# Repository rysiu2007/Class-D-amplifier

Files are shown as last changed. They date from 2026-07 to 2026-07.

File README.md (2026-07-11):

# Class-D Amplifier Learning Project

A discrete $200\text{kHz}$ triangle wave generator and Class-D amplifier stage built for learning analog layout and circuit design. 

## Current Status
* **Simulation:** LTspice transient simulations are verified but yet to finish.
* **Hardware:** KiCad PCB design is currently underway, optimized for single-layer hand-etching.

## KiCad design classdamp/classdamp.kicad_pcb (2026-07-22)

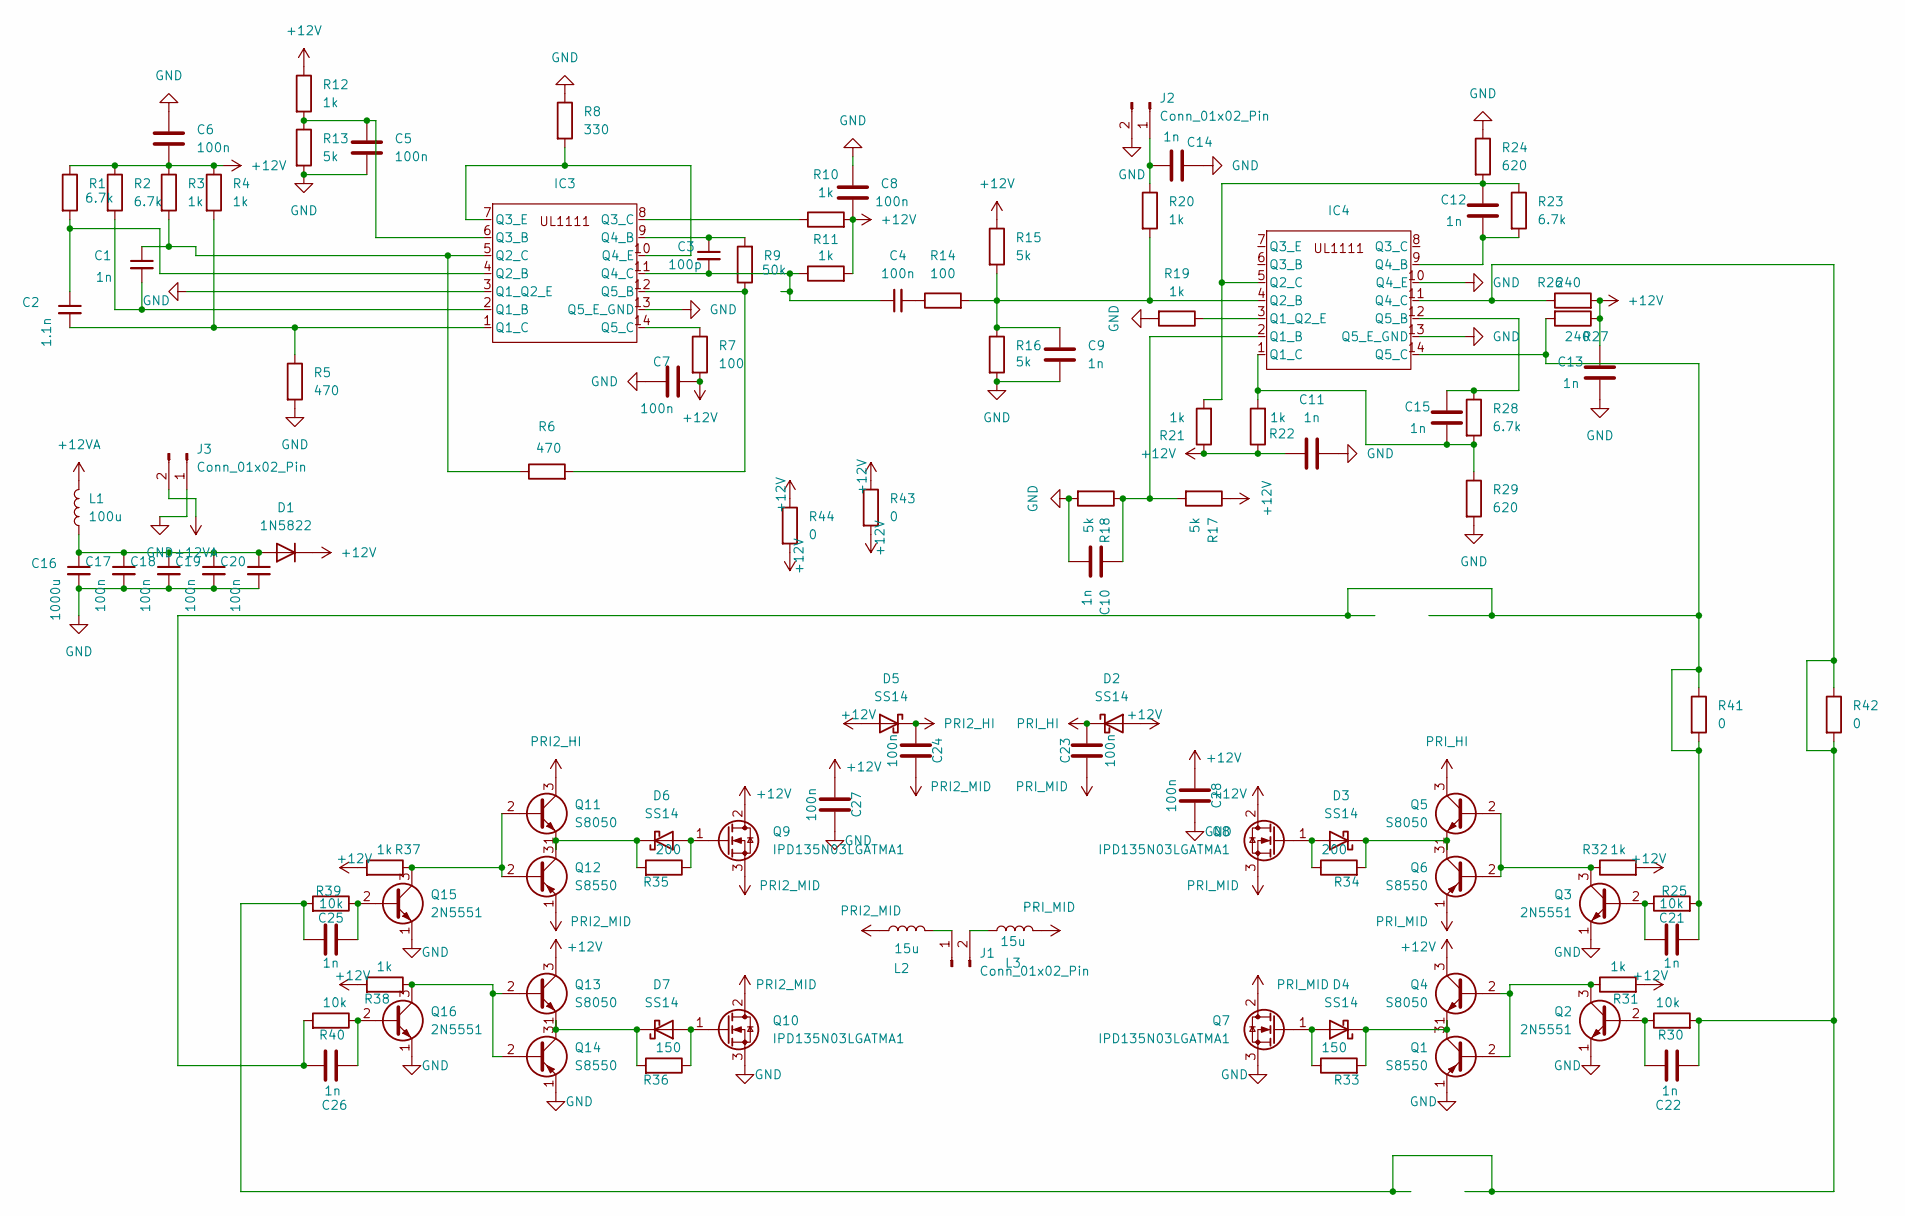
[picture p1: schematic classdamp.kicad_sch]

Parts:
C1, C9, C10, C11, C12, C13, C14, C15, C21, C22, C25, C26: 1n; C_Disc_D5.0mm_W2.5mm_P5.00mm
C2: 1.1n; C_Disc_D5.0mm_W2.5mm_P5.00mm
C3: 100p; C_Disc_D5.0mm_W2.5mm_P5.00mm
C4, C5, C6, C7, C8, C17, C18, C19, C20, C23, C24, C27, C28: 100n; C_Disc_D5.0mm_W2.5mm_P5.00mm
C16: 1000u; CP_Radial_D8.0mm_P3.50mm
D1: 1N5822; D_DO-35_SOD27_P7.62mm_Horizontal
D2, D3, D4, D5, D6, D7: SS14; D_SMA_Handsoldering
IC3, IC4: DIP-14_W7.62mm
J1, J2, J3: Conn_01x02_Pin; JWT_A3963_1x02_P3.96mm_Vertical
L1: 100u; L_Toroid_Horizontal_D24.1mm_P23.10mm_Bourns_2200
L2, L3: 15u; L_Radial_D10.0mm_P5.00mm_Fastron_07M
Q1, Q6, Q12, Q14: S8550; TO-92_Inline
Q2, Q3, Q15, Q16: 2N5551; TO-92_Inline
Q4, Q5, Q11, Q13: S8050; TO-92_Inline
Q7, Q8, Q9, Q10: IPD135N03LGATMA1; TO-252-2
R1, R2, R23, R28: 6.7k; R_Axial_DIN0207_L6.3mm_D2.5mm_P15.24mm_Horizontal
R3, R4, R10, R11, R12, R19, R20, R21, R22: 1k; R_Axial_DIN0207_L6.3mm_D2.5mm_P15.24mm_Horizontal
R5, R6: 470; R_Axial_DIN0207_L6.3mm_D2.5mm_P15.24mm_Horizontal
R7, R14: 100; R_Axial_DIN0207_L6.3mm_D2.5mm_P15.24mm_Horizontal
R8: 330; R_Axial_DIN0207_L6.3mm_D2.5mm_P15.24mm_Horizontal
R9: 50k; R_Axial_DIN0207_L6.3mm_D2.5mm_P15.24mm_Horizontal
R13, R15, R16, R17, R18: 5k; R_Axial_DIN0207_L6.3mm_D2.5mm_P15.24mm_Horizontal
R24, R29: 620; R_Axial_DIN0207_L6.3mm_D2.5mm_P15.24mm_Horizontal
R25, R30, R39, R40: 10k; R_Axial_DIN0204_L3.6mm_D1.6mm_P2.54mm_Vertical
R26, R27: 240; R_Axial_DIN0207_L6.3mm_D2.5mm_P15.24mm_Horizontal
R31, R32, R37, R38: 1k; R_Axial_DIN0204_L3.6mm_D1.6mm_P2.54mm_Vertical
R33, R36: 150; R_Axial_DIN0204_L3.6mm_D1.6mm_P2.54mm_Vertical
R34, R35: 200; R_Axial_DIN0204_L3.6mm_D1.6mm_P2.54mm_Vertical
R41, R42, R43, R44: 0; R_Axial_DIN0207_L6.3mm_D2.5mm_P15.24mm_Horizontal

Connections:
+12V: C6.2, C7.2, C8.2, C11.1, C13.1, C27.2, C28.2, D1.1 (K), D2.2 (A), D5.2 (A), Q4.3 (C), Q8.2 (D), Q9.2 (D), Q13.3 (C), R1.1, R2.1, R3.1, R4.1, R7.2, R10.2, R11.2, R12.1, R15.1, R17.1, R21.1, R22.1, R26.2, R27.1, R31.2, R32.2, R37.2, R38.2, R43.1, R43.2, R44.1, R44.2
+12VA: J3.2, L1.2
GND: C5.2, C6.1, C7.1, C8.1, C9.2, C10.2, C11.2, C13.2, C14.1, C16.2, C17.2, C18.2, C19.2, C20.2, C27.1, C28.1, IC3.3 (Q1_Q2_E), IC3.13 (Q5_E_GND), IC4.10 (Q4_E), IC4.13 (Q5_E_GND), J2.2, J3.1, Q1.1 (E), Q2.1 (E), Q3.1 (E), Q7.3 (S), Q10.3 (S), Q14.1 (E), Q15.1 (E), Q16.1 (E), R5.2, R8.1, R13.2, R16.2, R18.2, R19.2, R24.1, R29.2
unnamed: C4.2, R14.1
unnamed: C16.1, C17.1, C18.1, C19.1, C20.1, D1.2 (A), L1.1
unnamed: D3.2 (A), Q8.1 (G), R34.1
unnamed: D3.1 (K), Q5.1 (E), Q6.3 (C), R34.2
unnamed: D4.2 (A), Q7.1 (G), R33.1
unnamed: D4.1 (K), Q1.3 (C), Q4.1 (E), R33.2
unnamed: D6.2 (A), Q9.1 (G), R35.1
unnamed: D6.1 (K), Q11.1 (E), Q12.3 (C), R35.2
unnamed: D7.2 (A), Q10.1 (G), R36.1
unnamed: D7.1 (K), Q13.1 (E), Q14.3 (C), R36.2
unnamed: C1.2, IC3.2 (Q1_B), R2.2
unnamed: C2.2, IC3.1 (Q1_C), R4.2, R5.1
unnamed: C2.1, IC3.4 (Q2_B), R1.2
unnamed: C1.1, IC3.5 (Q2_C), R3.2, R6.1
unnamed: C5.1, IC3.6 (Q3_B), R12.2, R13.1
unnamed: IC3.8 (Q3_C), R10.1
unnamed: IC3.7 (Q3_E), IC3.10 (Q4_E), R8.2
unnamed: C3.1, IC3.9 (Q4_B), R9.2
unnamed: C3.2, C4.1, IC3.11 (Q4_C), R11.1
unnamed: IC3.12 (Q5_B), R6.2, R9.1
unnamed: IC3.14 (Q5_C), R7.1
unnamed: C10.1, IC4.2 (Q1_B), R17.2, R18.1
unnamed: C15.2, IC4.1 (Q1_C), R22.2, R28.2, R29.1
unnamed: IC4.3 (Q1_Q2_E), R19.1
unnamed: C9.1, IC4.4 (Q2_B), R14.2, R15.2, R16.1, R20.2
unnamed: C12.1, IC4.5 (Q2_C), R21.2, R23.1, R24.2
unnamed: C12.2, IC4.9 (Q4_B), R23.2
unnamed: C22.2, C25.2, IC4.11 (Q4_C), R26.1, R30.2, R39.2, R42.1, R42.2
unnamed: C15.1, IC4.12 (Q5_B), R28.1
unnamed: C21.2, C26.2, IC4.14 (Q5_C), R25.2, R27.2, R40.2, R41.1, R41.2
unnamed: J1.1, L2.2
unnamed: J1.2, L3.1
unnamed: C14.2, J2.1, R20.1
unnamed: Q1.2 (B), Q2.3 (C), Q4.2 (B), R31.1
unnamed: C22.1, Q2.2 (B), R30.1
unnamed: C21.1, Q3.2 (B), R25.1
unnamed: Q3.3 (C), Q5.2 (B), Q6.2 (B), R32.1
unnamed: Q11.2 (B), Q12.2 (B), Q15.3 (C), R37.1
unnamed: Q13.2 (B), Q14.2 (B), Q16.3 (C), R38.1
unnamed: C25.1, Q15.2 (B), R39.1
unnamed: C26.1, Q16.2 (B), R40.1
PRI2_HI: C24.2, D5.1 (K), Q11.3 (C)
PRI2_MID: C24.1, L2.1, Q9.3 (S), Q10.2 (D), Q12.1 (E)
PRI_HI: C23.2, D2.1 (K), Q5.3 (C)
PRI_MID: C23.1, L3.2, Q6.1 (E), Q7.2 (D), Q8.3 (S)

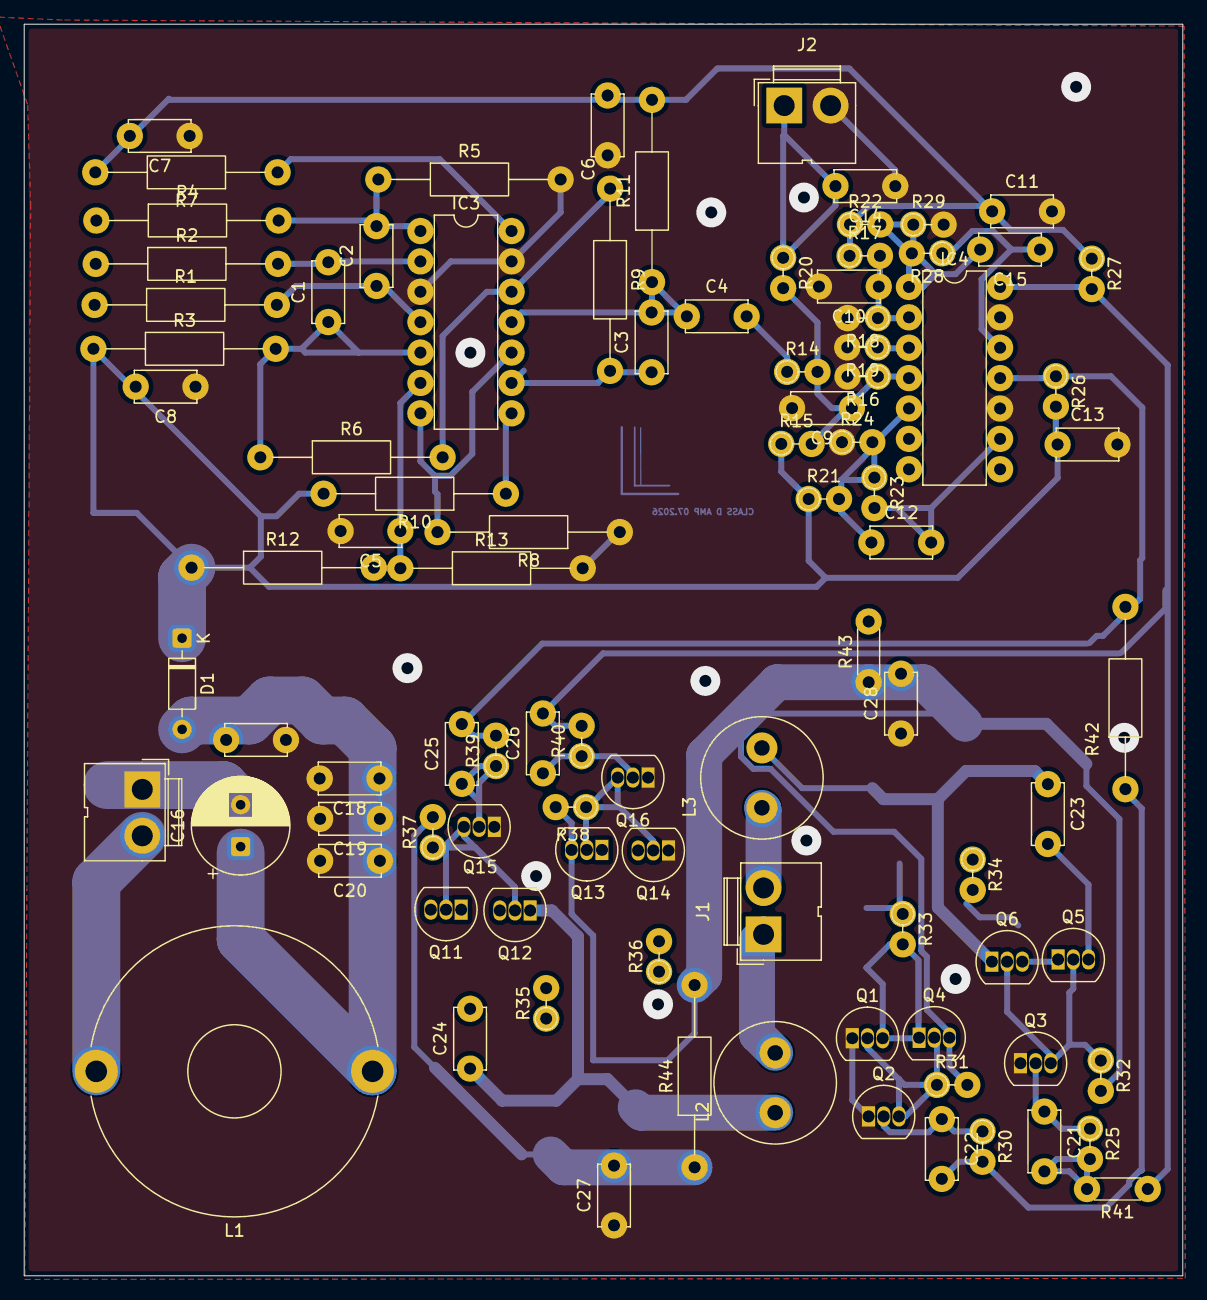
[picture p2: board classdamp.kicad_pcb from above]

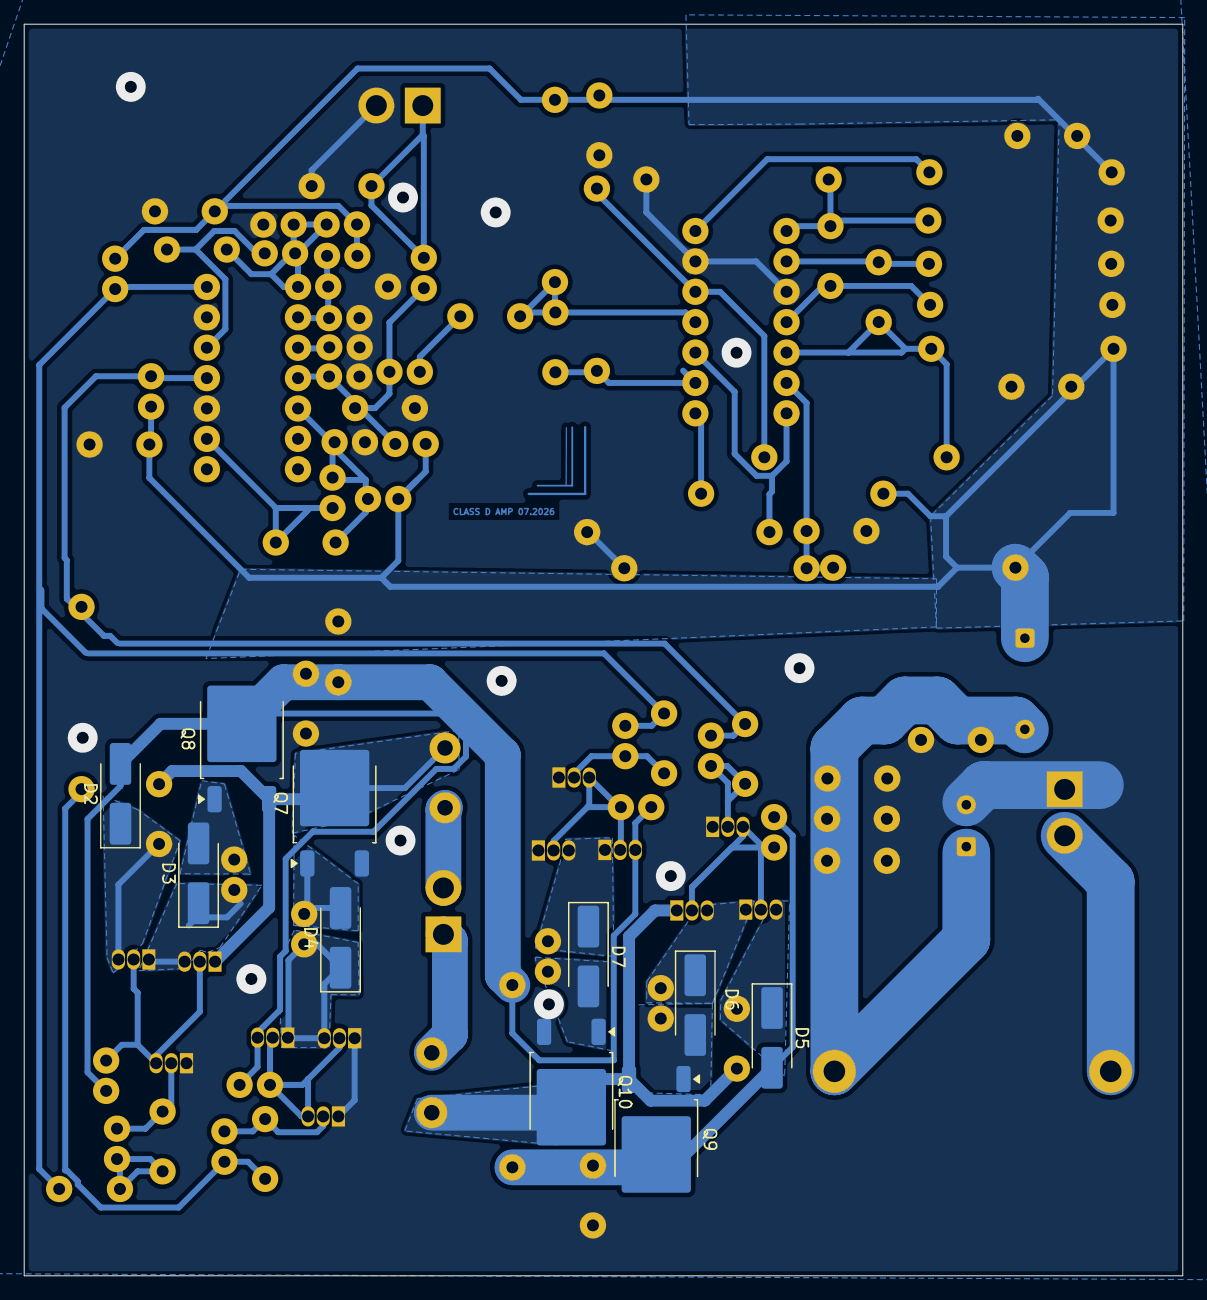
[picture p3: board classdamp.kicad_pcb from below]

Board: 2 copper layers, 96.9 x 104.6 mm, 103 parts (10 on the bottom side), 48 nets.

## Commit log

2026-07-11 LTspice schematic
2026-07-11 Comparator stage
    [classdamp.kicad_pcb, classdamp.kicad_sch]
2026-07-11 Low power side done
    [classdamp.kicad_pcb]
2026-07-11 Pcb update
    [classdamp.kicad_pcb]
2026-07-16 Test drawing in pcb and circuit fixes
    [classdamp.kicad_pcb, classdamp.kicad_sch]
2026-07-20 Adding discrete output stage to SPICE and minor circuit fixes
2026-07-22 PCB design done
    [classdamp.kicad_pcb, classdamp.kicad_sch]
